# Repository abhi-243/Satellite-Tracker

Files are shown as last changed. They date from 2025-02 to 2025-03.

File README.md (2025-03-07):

# 📡 Amateur Radio Satellite Tracking System

A budget-friendly solution for amateur radio enthusiasts to **track and listen to satellite data and communications** by automatically adjusting an antenna rotator to match a satellite's azimuth and elevation in real time.

---

## 🚀 How It Works

1. **Tracking Data Input**
   - Uses [Orbitron](https://www.stoff.pl/) to output azimuth (bearing) and elevation (height) data via serial.

2. **Microcontroller & Motor Control**
   - An **ESP32 microcontroller** reads target values from Orbitron.
   - Stepper motor drivers convert these values into precise movements.

3. **Position Feedback & Adjustment**
   - **Magnetometer** measures the current azimuth.
   - **Potentiometer** measures the current elevation.
   - Stepper motors adjust the antenna **until the real position matches the target values**.

4. **User Interaction & Control**
   - Users can enter target values via **serial input** or fine-tune with **rotary encoders**.
   - An **LCD screen** displays the current and target azimuth/elevation values in real time.

---

## 🔧 Features  

✔️ **Automatic satellite tracking** with Orbitron  
✔️ **Real-time position correction** with sensor feedback  
✔️ **Manual fine-tuning** via rotary encoders  
✔️ **Live tracking display** on an LCD screen  
✔️ **ESP32-based system** for affordability and flexibility  

---

## 🛠 Hardware Requirements

- **ESP32** microcontroller  
- **Stepper motors & drivers**  
- **Magnetometer** (for azimuth sensing)  
- **Potentiometer** (for elevation sensing)  
- **Rotary encoders** (for manual control)  
- **LCD screen** (for real-time data display)  
- **Antenna & mounting system**  

---

## 📜 Getting Started  

1. Install **Orbitron** and configure it to output azimuth/elevation data over serial.  
2. Flash the **ESP32 firmware** from this repository.  
3. Connect the hardware as per the wiring diagram.  
4. Use the **serial interface or rotary encoders** to control and monitor the system.  

---

## 📖 License  

This project is open-source and available under the **MIT License**.

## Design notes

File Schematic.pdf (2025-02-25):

3V3 | GND
EN | GPIO23
GPIO36 | GPIO22
GPIO39 | GPIO1
GPIO34 | GPIO3
GPIO35 | GPIO21
GPIO32 | GND
GPIO33 | GPIO19
GPIO25 | GPIO18
GPIO26 | GPIO5
GPIO27 | GPIO17
GPIO14 | GPIO16
GPIO12 | GPIO4
GND | GPIO0
GPIO13 | GPIO2
GPIO9 | GPIO15
GPIO10 | GPIO8
GPIO1
1 | GPIO7
5V | GPIO6

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
EN | MOT
MS1 | GND
MS2 | 2B
MS3 | 2A
RST | 1B
SLP | 1A
STEP | VDD
DIR | GND

COIL 2B
COIL 2A
COIL 1B
COIL 1A
EN | MOT
MS1 | GND
MS2 | 2B
MS3 | 2A
RST | 1B
SLP | 1A
STEP | VDD
DIR | GND

COIL 2B
COIL 2A
COIL 1B
COIL 1A

10k

Ω

10k

Ω

100uf

100uf

24V

Magnetometer

LiquidCrystal Display

Encoder1

Encoder2

Potentiometer

Stepper Motor1

Stepper Motor2

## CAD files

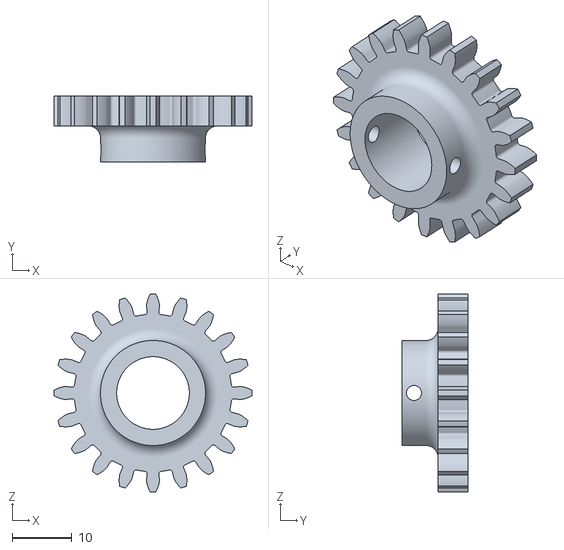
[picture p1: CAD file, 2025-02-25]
Files/MainGear.stl
33.0 x 11.0 x 33.0

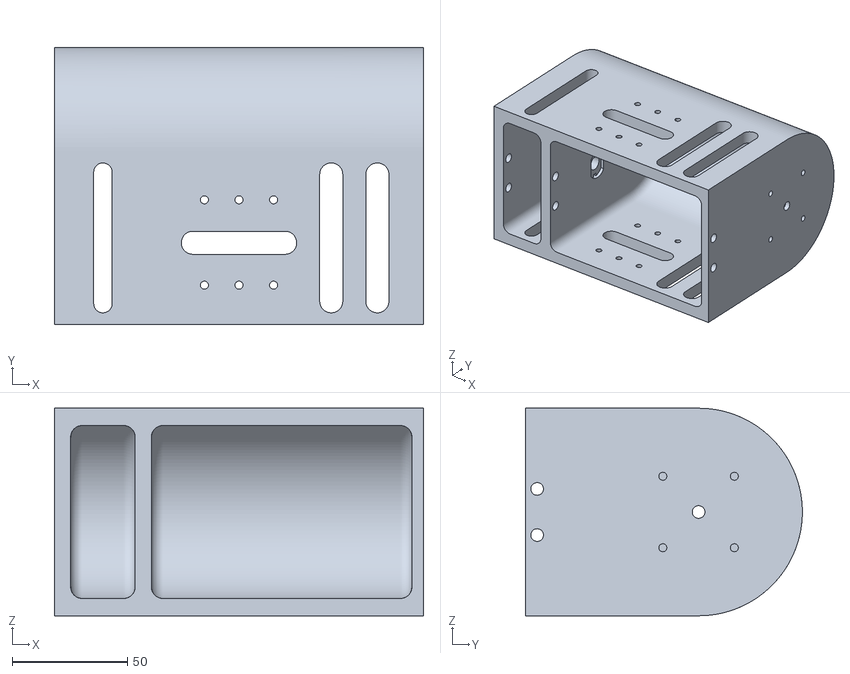
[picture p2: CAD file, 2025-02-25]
Files/Main Body.stl
160.0 x 120.0 x 90.0

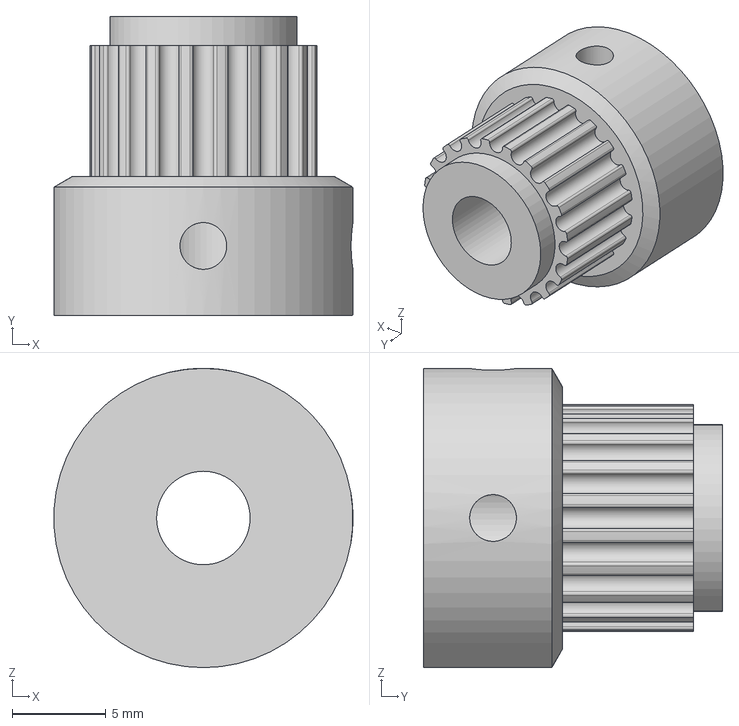
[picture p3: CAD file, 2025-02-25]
CAD Files/GT2+20T.stp
16.0 x 16.0 x 16.0 mm

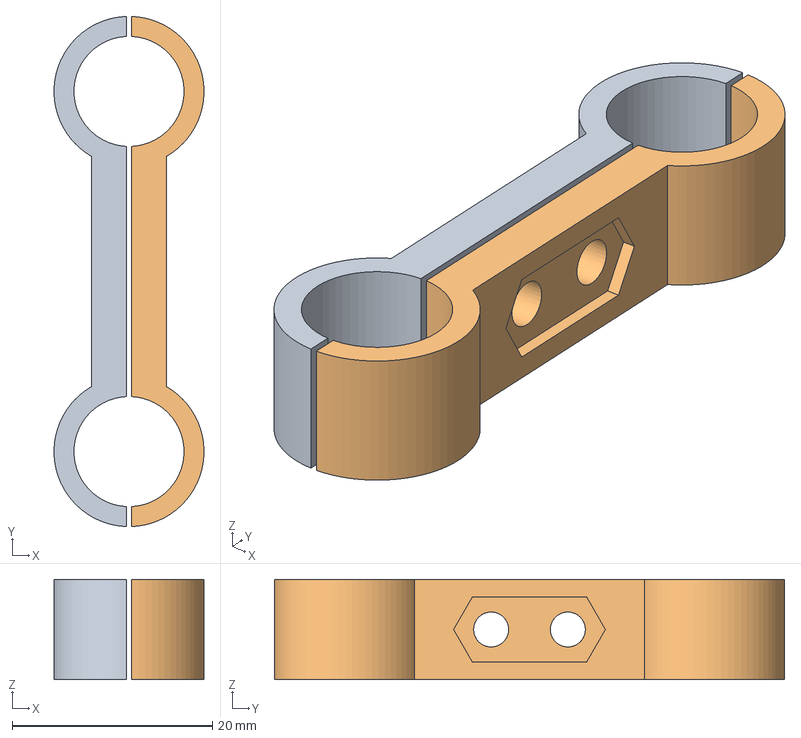
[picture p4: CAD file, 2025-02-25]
Files/Spacer.3mf
15.0 x 51.0 x 10.0 mm

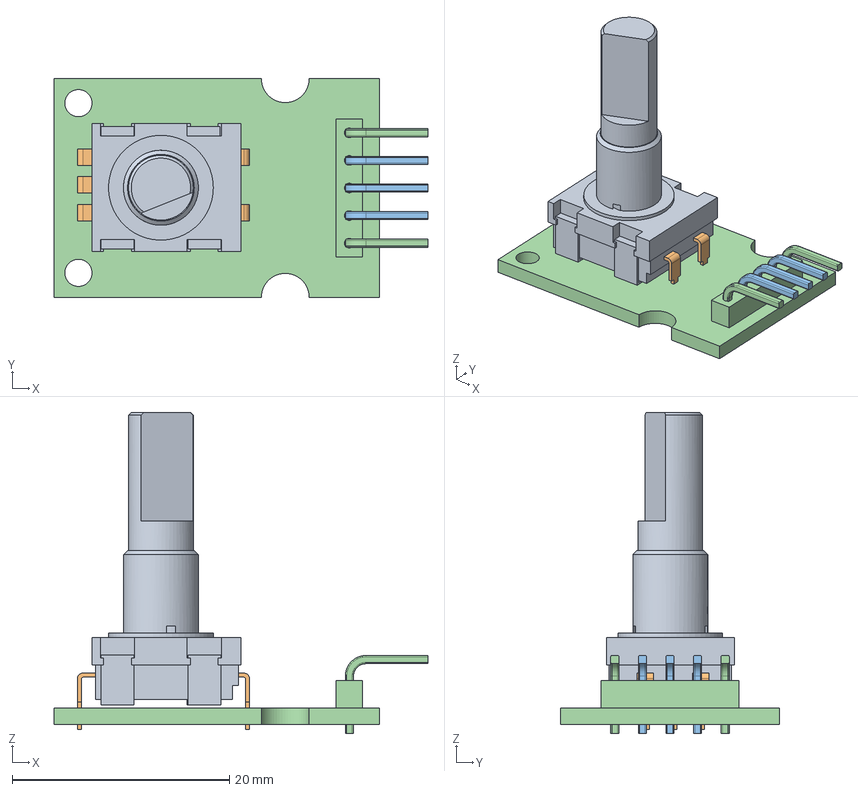
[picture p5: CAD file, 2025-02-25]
CAD Files/Rotary+Encoder.stp
34.4 x 20.1 x 29.6 mm
mtg flange
body_encoder
5 pin header
90d pin_header x 5
pins_encoder body_2 x 5
shaft_encoder

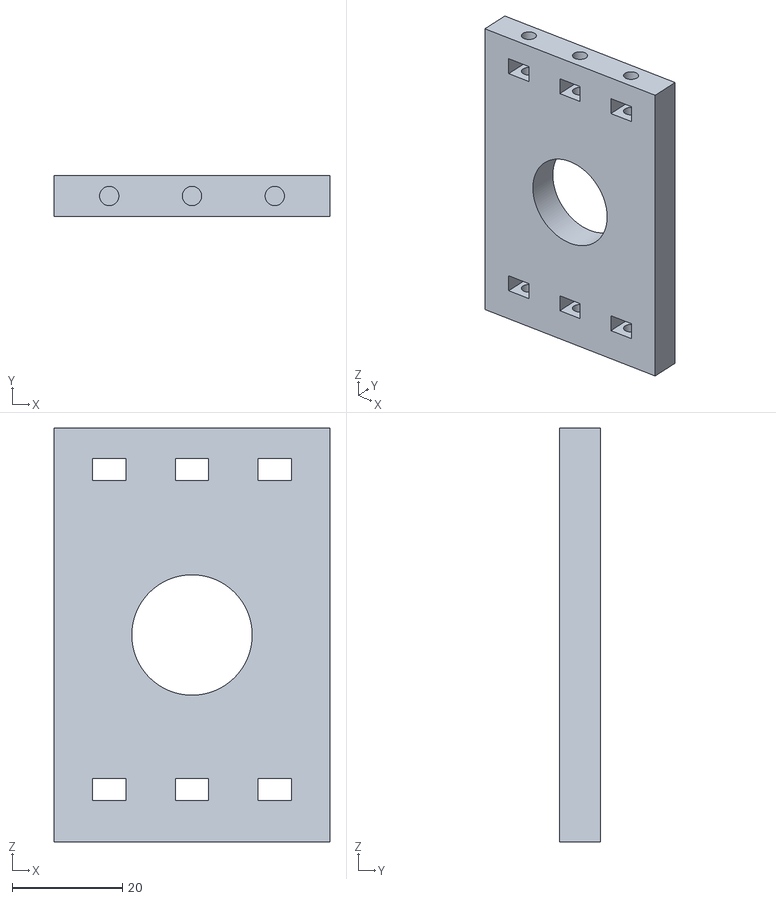
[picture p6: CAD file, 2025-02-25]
Files/Bearing Mount.stl
50.0 x 7.50 x 75.0

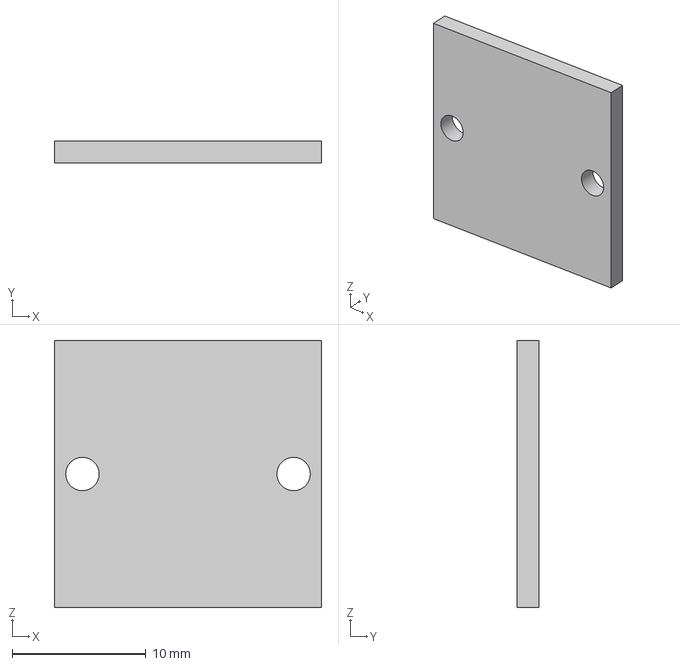
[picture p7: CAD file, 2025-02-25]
CAD Files/QMC5883L.stp
20.0 x 1.64 x 20.0 mm

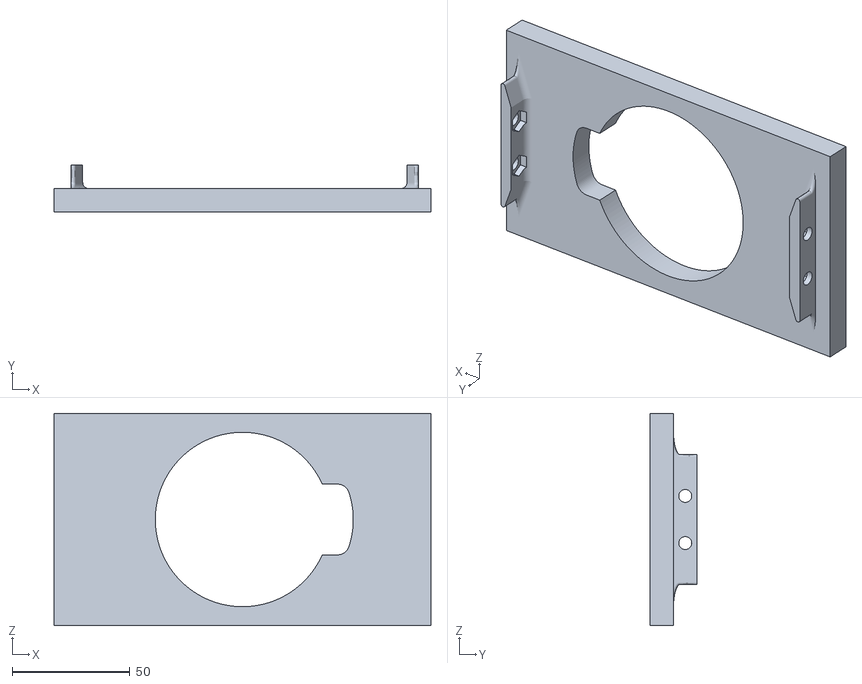
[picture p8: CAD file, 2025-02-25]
Files/Bottom Plate.stl
160.0 x 20.0 x 90.0

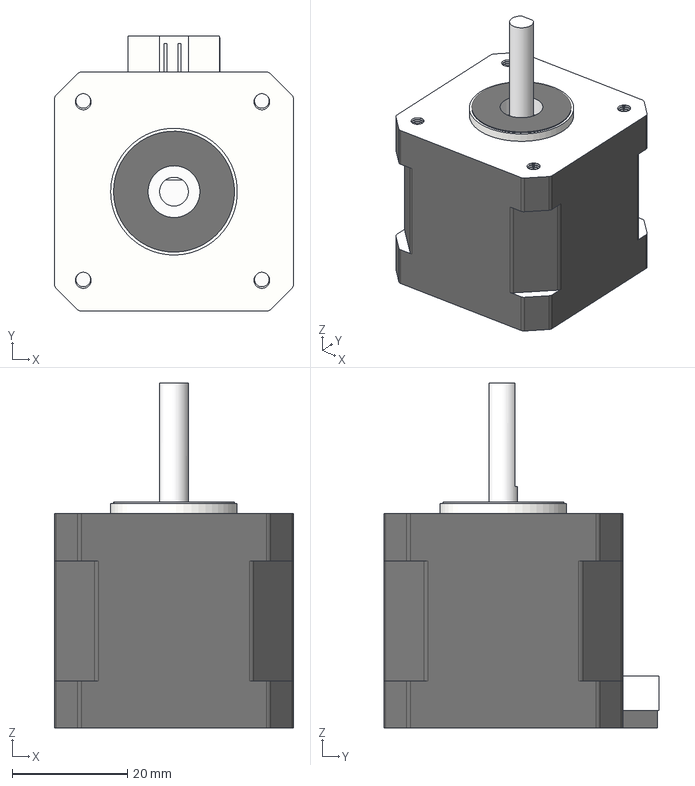
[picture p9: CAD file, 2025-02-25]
CAD Files/NEMA+17.stp
41.5 x 47.8 x 59.9 mm

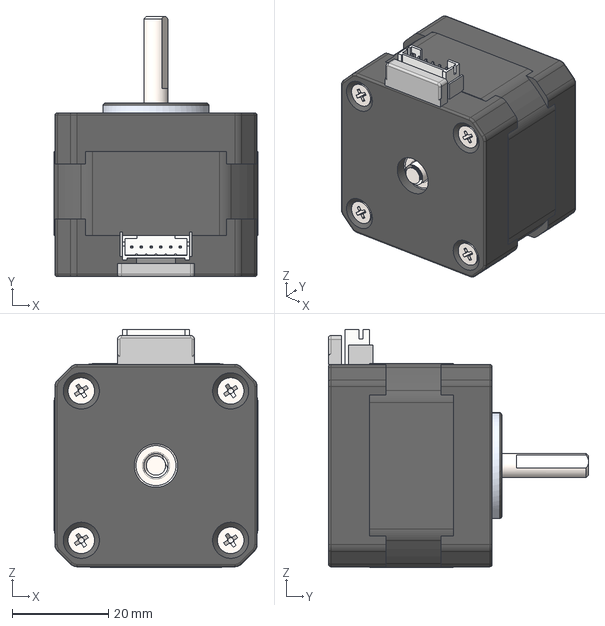
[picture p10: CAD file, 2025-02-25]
CAD Files/NEMA+17+-+34mm.stp
42.3 x 54.0 x 49.4 mm

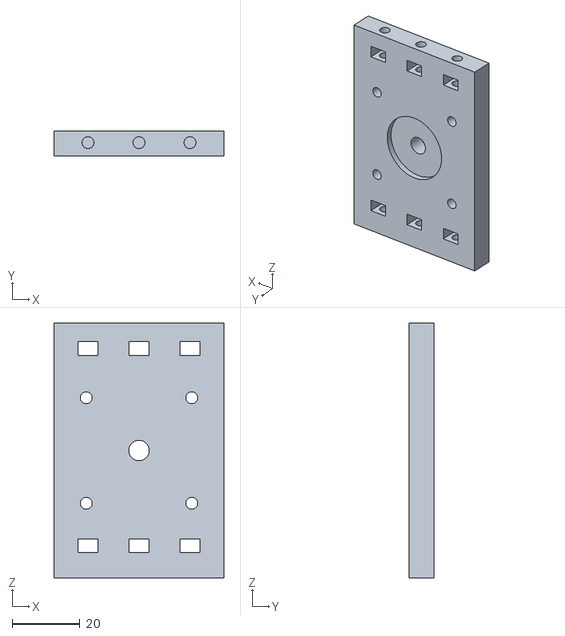
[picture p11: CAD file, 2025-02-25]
Files/Stepper Mount.stl
50.0 x 7.50 x 75.0

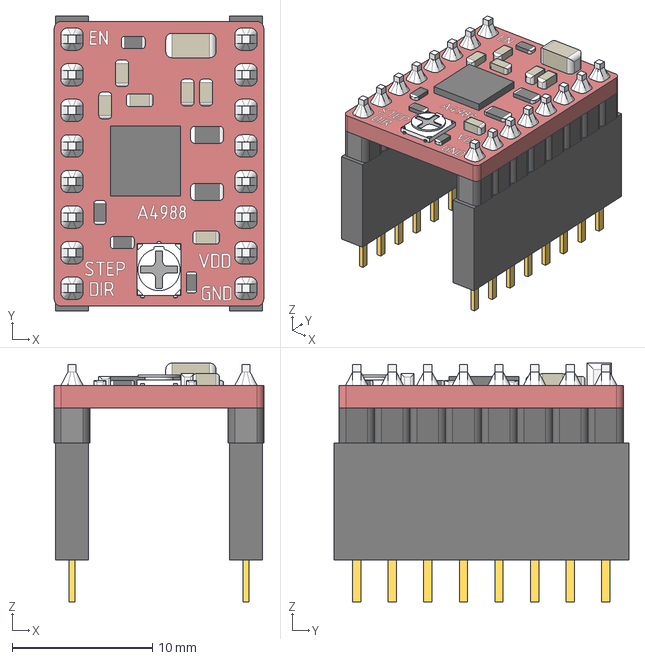
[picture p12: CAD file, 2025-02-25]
CAD Files/A4988+Stepper+Driver.stp
15.0 x 21.1 x 17.1 mm

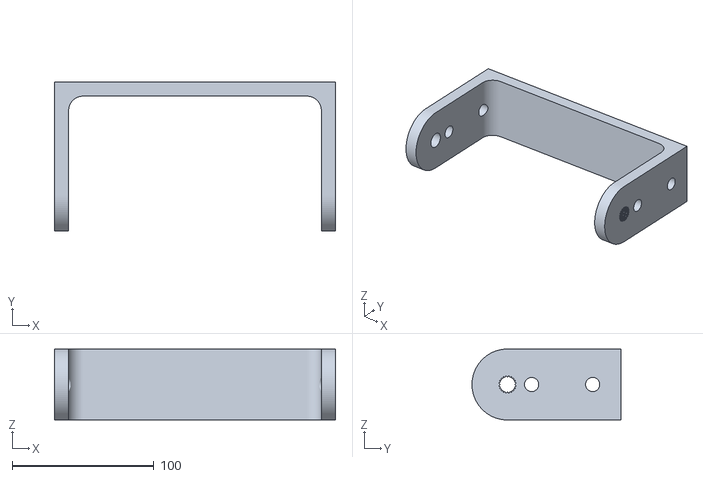
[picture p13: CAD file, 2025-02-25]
Files/Elevation Arm.stl
198.0 x 105.0 x 50.0

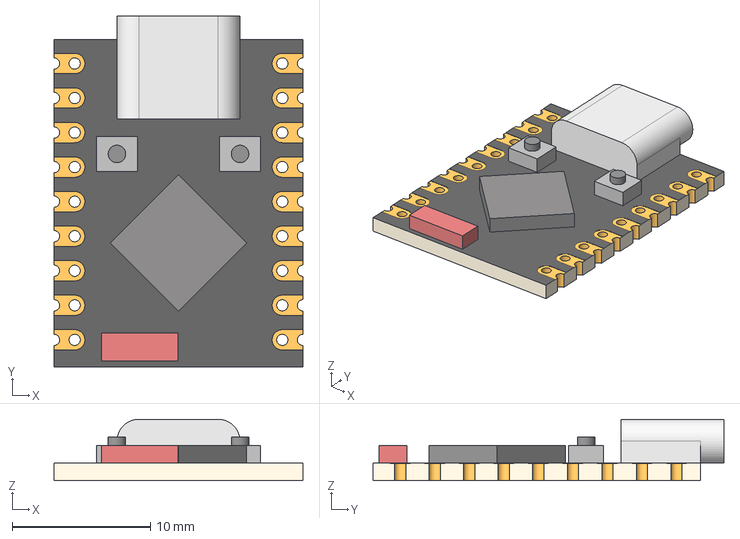
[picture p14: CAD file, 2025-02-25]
CAD Files/ESP32S3+Super+Mini.stp
18.0 x 25.4 x 4.45 mm

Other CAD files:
Files/PotGear.stl
CAD Files/UHF+Connector.stp
Files/Claw.stl
CAD Files/Shaft+Collar.stp
CAD Files/5X8_COUPLER.stp
CAD Files/Potentiometer.stp
CAD Files/Yagi+2m_70cm.stp
Files/Azimuth Rotator.stl
Files/Base.stl
Files/Connector.stl
Files/Connector_Gear.stl
Files/Electronics Box.stl
Files/Electronics Lid.stl
Files/PSU Box.stl
Files/PSU Lid.stl
Files/Rings.stl
Files/Servo_Connector_Gear.stl

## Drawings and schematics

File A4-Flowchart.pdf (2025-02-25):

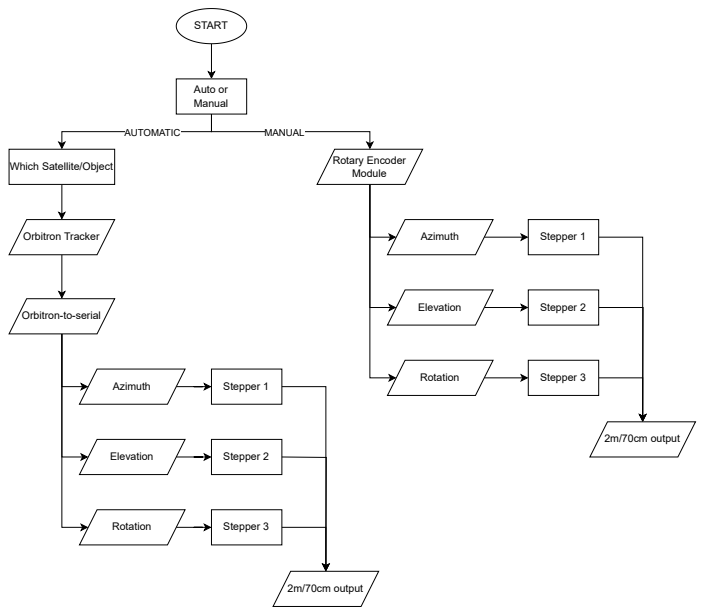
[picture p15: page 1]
START; AUTOMATIC; MANUAL; Auto or Manual; Which Satellite/Object; Rotary Encoder; Module; Azimuth; Elevation; Rotation; Orbitron Tracker; Stepper 1; Stepper 2; Stepper 3; 2m/70cm output

Orbitron-to-serial

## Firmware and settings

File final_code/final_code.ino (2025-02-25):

#include "AccelStepper.h"
#include "QMC5883LCompass.h"
#include <Wire.h>
#include <LiquidCrystal_I2C.h>

// Define stepper motor connections and motor interface type. 
// Motor interface type must be set to 1 when using a driver
#define dirPin1 16
#define stepPin1 17
#define dirPin2 18
#define stepPin2 19
#define motorInterfaceType 1

//Encoder Pins
#define CLK1 33
#define DT1 32
#define SW1 35

#define CLK2 34
#define DT2 39
#define SW2 36

#define potPin 27

// Create instances of the AccelStepper class for each motor:
AccelStepper azStepper = AccelStepper(motorInterfaceType, stepPin1, dirPin1);
AccelStepper elStepper = AccelStepper(motorInterfaceType, stepPin2, dirPin2);

// Initialize the LCD, assuming it's a 16x2 LCD with I2C address 0x27
LiquidCrystal_I2C lcd(0x27, 16, 2);

// Magnetometer object
QMC5883LCompass compass;

//variables for printing
float azimuth = 0.0;
float elevation = 0.0;
String inputString = ""; // To store the input string


//logic variables
float azTarget = 0.0;
float elTarget = 0.0;
float azCurrent = 0.0;
float elCurrent = 0.0;
int azPosition = 0;
int elPosition = 0;
int azPre = -1;
int elPre = -1;
int az = 0;
int el = 0;

//more logic variables
bool azStop = false;
bool elStop = false;
int azDeadZone = 5;
int elDeadZone = 10;

//elevation pot
int potValue = 0;


void setup() {
  Serial.begin(9600);

  
  // Set the maximum speed and acceleration for both steppers:
  azStepper.setMaxSpeed(200);
  azStepper.setAcceleration(70);
  elStepper.setMaxSpeed(200);
  elStepper.setAcceleration(70);

  //begin the compass
  compass.init();
  
  //compass calibrations
  compass.setCalibrationOffsets(1850.00, -1740.00, -1297.00);
  compass.setCalibrationScales(0.92, 0.98, 1.12);

  // Initialize the LCD
  lcd.init();
  lcd.clear();
  lcd.backlight();

  // Clear LCD and set up initial display
  lcd.clear();
  lcd.setCursor(0, 0);
  lcd.print("Ac:-----At:-----");
  lcd.setCursor(0, 1); 
  lcd.print("Ec: ----Et: ----");
}

void loop() {
  // Display the values on the LCD
  displayValues();

  // Check if data is available on Serial
  if (Serial.available() > 0) {
    // Read the incoming string until the newline character
    inputString = Serial.readStringUntil('\n');

    // Parse the azimuth and elevation from the string
    parseAZEL(inputString);
  }

  //
  potValue = analogRead(potPin);
  el = map(potValue, 1637, 3570, 0, 90);
  el = constrain(el, 0, 90);

  if(abs(el - elPre) >= 2) {
    elPre = el;
    elCurrent = el;
  }

  elPosition = (elTarget - elCurrent) * 200;
  if(elTarget <= 0) {
    elTarget = 0;
  }


  compass.read();

  az = compass.getAzimuth();

  if(abs(az - azPre) >= 3) {
    azPre = az;
    azCurrent = az;
  }

  if (azCurrent < 0) {
    azCurrent += 360;
  }


  if(elCurrent == elTarget) {
    elStepper.stop();
    elStop = true;
  } else if(abs(elCurrent - elTarget)>=elDeadZone) {
    elStop = false;
    if(elCurrent < elTarget) {
      elStepper.setSpeed(300);
    } else if(elCurrent > elTarget) {
      elStepper.setSpeed(-300);
    }
    elStepper.moveTo(elPosition);
    elStepper.run();
  }


  azPosition = (azTarget - azCurrent) * 200;

  if(azCurrent == azTarget) {
    azStepper.stop();
    azStop = true;
  } else if(abs(azCurrent - azTarget)>=azDeadZone) {
    azStop = false;
    if(azCurrent < azTarget) {
      azStepper.setSpeed(300);
    } else if(azCurrent > azTarget) {
      azStepper.setSpeed(-300);
    }
    azStepper.moveTo(azPosition);
    azStepper.run();
  }

}



void parseAZEL(String data) {
  int azIndex = data.indexOf("AZ: ");
  int elIndex = data.indexOf(", EL: ");

  if (azIndex != -1 && elIndex != -1) {
    // Extract the azimuth and elevation substrings
    String azString = data.substring(azIndex + 4, elIndex);
    String elString = data.substring(elIndex + 6);

    // Convert the strings to floats
    azimuth = azString.toFloat();
    elevation = elString.toFloat();
    azTarget = constrain(azimuth, 0.0, 359.0);
    elTarget = elevation;
  }
}


// Function to display azimuth and elevation on the LCD
void displayValues() {
  // Correct cursor positions in displayValues()
  lcd.setCursor(3, 0);  // Current azimuth at (3, 0)
  lcd.print("     ");
  lcd.setCursor(3, 0);
  lcd.print(azCurrent, 1);

  lcd.setCursor(3, 1);  // Current elevation at (3, 1)
  lcd.print("     ");
  lcd.setCursor(3, 1);
  lcd.print(elCurrent, 1);

  lcd.setCursor(11, 0); // Target azimuth at (11, 0)
  lcd.print("     ");
  lcd.setCursor(11, 0);
  lcd.print(azTarget, 1);

  lcd.setCursor(11, 1); // Target elevation at (11, 1)
  lcd.print("     ");
  lcd.setCursor(11, 1);
  lcd.print(elTarget, 1);

}
